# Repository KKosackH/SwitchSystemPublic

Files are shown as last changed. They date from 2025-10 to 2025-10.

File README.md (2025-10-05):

# SwitchSystem  
**NOTE: Files with parts under NDA has been removed**

The **SwitchSystem** PCB was developed as an *add-on discharging solution* for existing **AC home chargers**.  

Although the concept worked, the product was ultimately deemed too **expensive** for production. As a result, the design has been made publicly available.  

All major components were tested and verified functional, including the **HomePlug Green PHY (PLC communication)** with negligible switching losses. However, the PCB was not fully finalized — see the [TO-DO](#to-do) list below for pending improvements.  

---

## Features  
- **Discharging add-on** for existing AC chargers  
- **PLC communication** via HomePlug Green PHY  
- **Integration with Raspberry Pi** through a 2×20 GPIO connector  
- **BatteryBridge compatibility** via JST connector  
- **External I/O**: LCD screen and buttons via JST  
- **Vehicle interface**: IEC 62196 Type 2 AC plug with temperature sensor and lock  
- **Inverter interface**: CANBus development board mounted on Raspberry Pi  

---

## Design Notes  
- The board was later split into multiple PCBs to:  
  - Avoid routing **AC mains** directly onto the main board  
  - Reduce **EMI issues**  
- The newer versions (under NDA) added advanced features such as:  
  - **LTE Cat 4 module**  
  - **CANBus support**  
  - **AMD Xilinx Zynq 7000 SoC**  

> ⚠️ If using the **BatteryBridge v2**, remove the `[3.4] DC-DC converter` and patch the **12 V output** of the BatteryBridge to the 12 V net on the SwitchSystem PCB.  

A full circuit description is available in the [Documentation folder](./Documentation).  

---

## Schematic & PCB  

The schematic is organized using hierarchical sheets, with the root page showing all user-interactable components.  

- **First page schematic**  
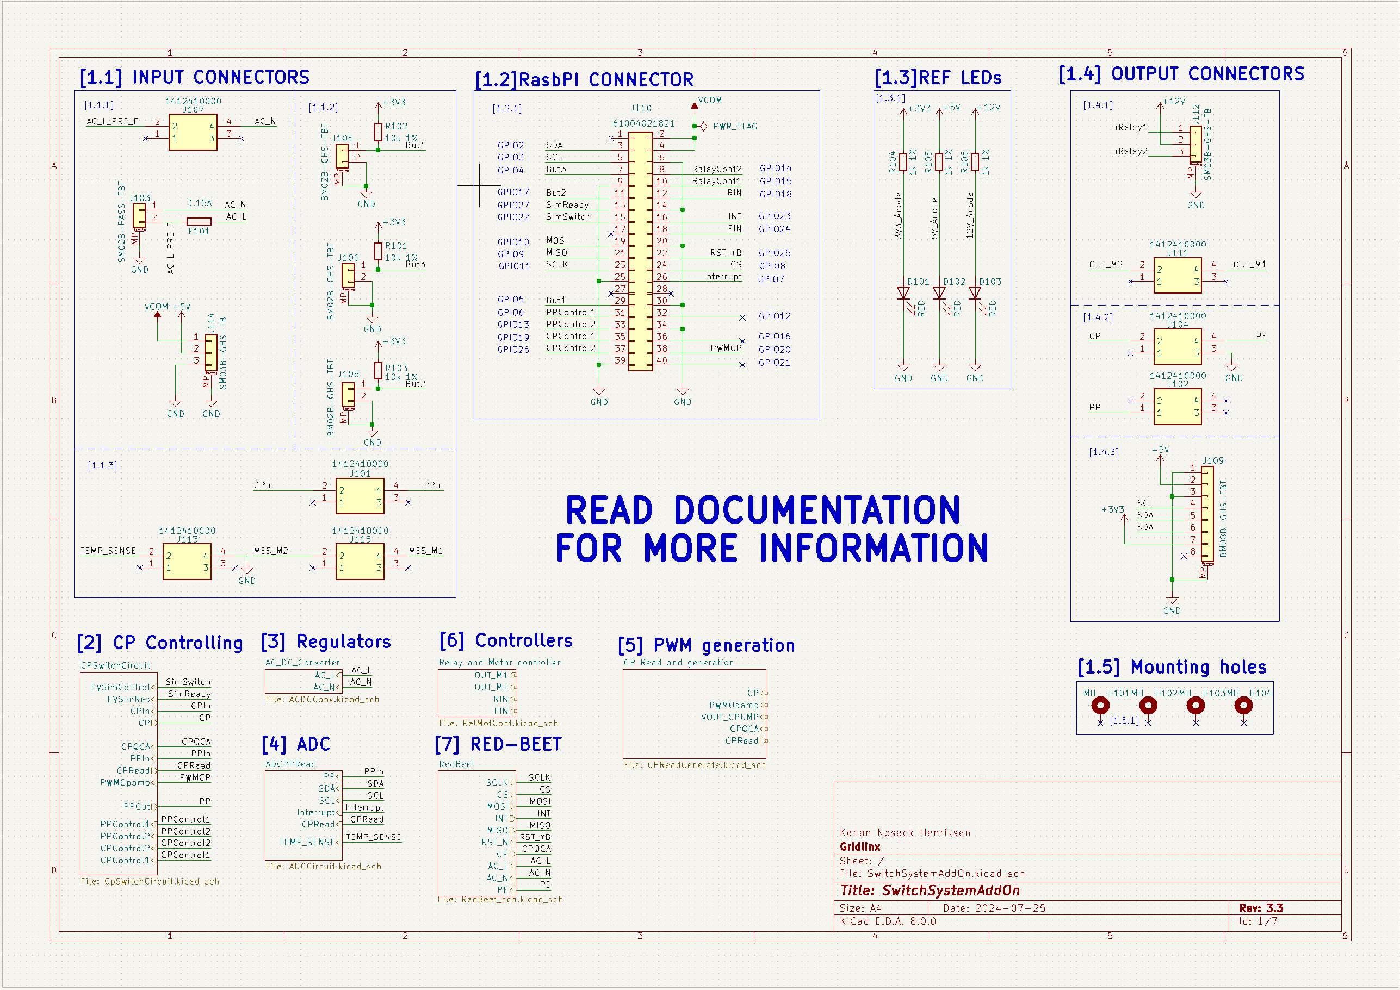
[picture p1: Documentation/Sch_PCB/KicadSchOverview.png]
Schematic Overview
    

- **PCB Front**  
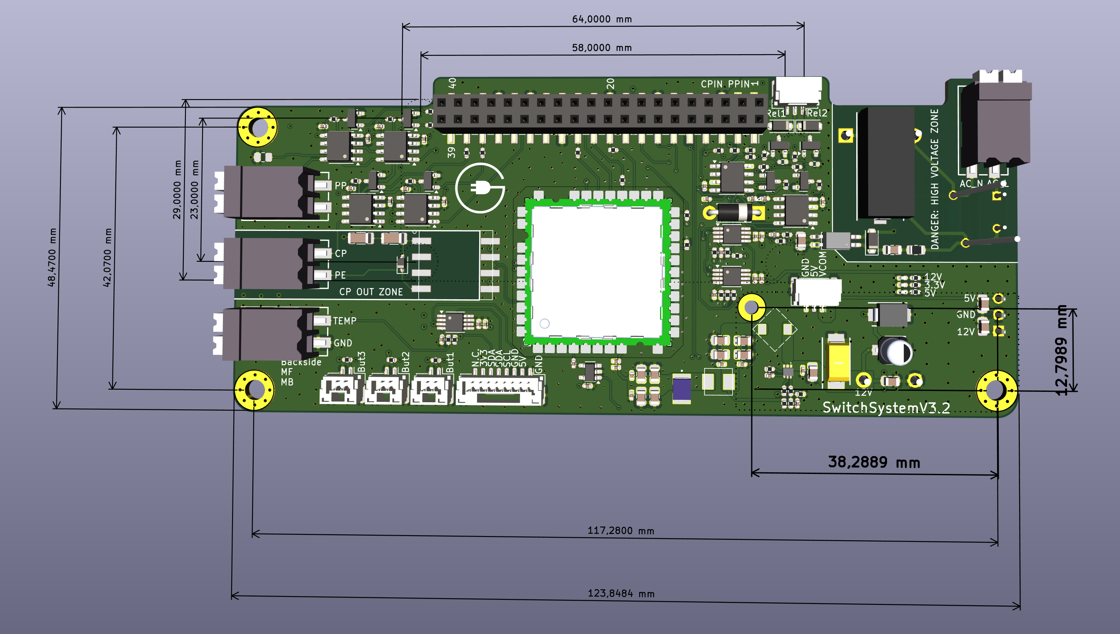
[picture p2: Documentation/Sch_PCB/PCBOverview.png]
PCB Front
    

- **PCB Back**  
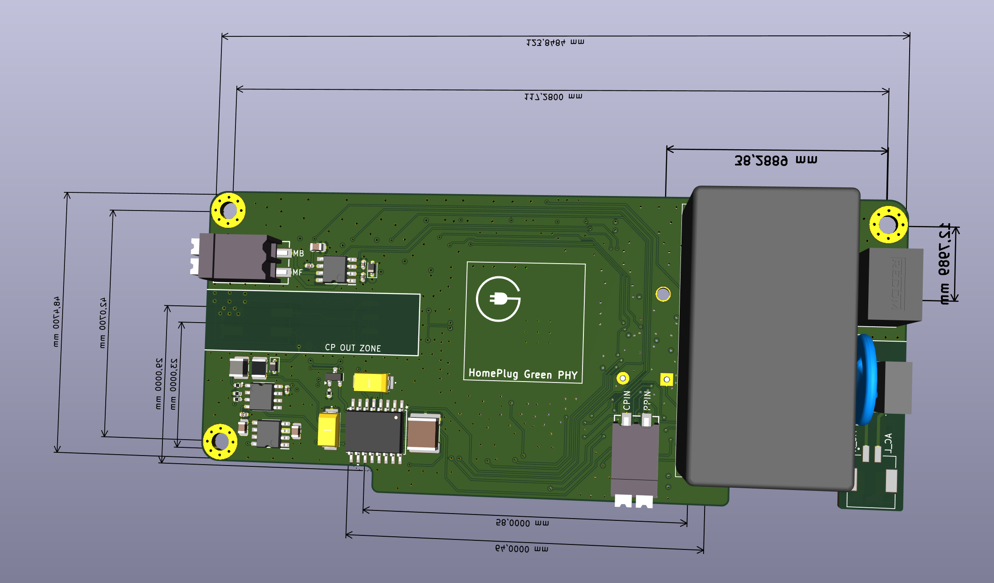
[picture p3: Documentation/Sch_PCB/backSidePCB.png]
PCB Back
    

---

## TO-DO  
Remaining improvements for the PCB design:  

1. Add node names to all nets  
2. Ensure all schematic symbols have correct naming  
3. Add transfer vias  
4. Match SPI line lengths  
5. Change BatteryBridge connector to flat-flex  
6. Add new ADC and connect to motor measurement  
7. Add color coding for cables on PCB  
8. Add low-pass filter to CPRead ADC  
9. Add protected earth connector  
10. Add default charge state for power-loss events  
11. Adjust PCB size for mechanically stable Raspberry Pi mounting  

---

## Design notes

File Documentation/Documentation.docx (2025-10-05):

V3.3 PCB description and documentation
Kenan Henriksen
Gridlinx

07/11-2024

# Overview of components

# SHEET NUMBER 1

## [1.1] Input connectors

## [1.1.1] Power input connectors

  - Screw terminal J107 for AC-mains input
  - SM02B connector J103 for AC connection from EVSE
  - SM03B connector J114 for BatteryBridge connection

## [1.1.2] UI inputs from buttons

  - J105 for button 1
  - J106 for button 2
  - J108 for button 3

## [1.1.3] Type-2 plug inputs

  - J101 terminal for CP- and PP input from EVSE
  - J113 terminal for temperature sensor input
  - J115 terminal for motor state measurement

## [1.1] Detailed Description

## [1.1.1]

The connectors in [1.1.1] are all power input connectors. The J103 is the main AC connector, when using power from the EVSE. This must be connected to the input side of the relay, which will power the PCB from the EVSE. Alternatively, the J107 connector can be used, if the mains will be directly connected to the PCB instead of through the EVSE.
NOTE: Both must never be attached at the same time.

The J114 is used to connecting the BatteryBridge, ensuring that 12V, 3.3V and 5V will always be available, even in the case of a power outage.

## [1.1.2]

The buttons can be used to change the state of the add-on. If button 1/2/3 (J105, J106, J108) is pressed, the following GPIO inputs will be pulled LOW: GPIO5, GPIO17, GPIO4.

The current configuration only uses 2 buttons (1 and 2), which respectively change to state charging and discharging.

## [1.1.3]

The J101 connector is used for connecting the CP and PP lines from the EVSE. The CP line is connected by the WHITE cable from the plug, and the BLACK cable for the PP line.

The J113 line is used for connecting the temperature sensor. The GREY cable is used for the measurement and the BROWN is used for GROUND. The output is connected to the temperature ADC [4.1.2].

Note: The following resistances is given for different conditions:
IF (TEMP < 110) THEN R == 790 to 1279

IF (TEMP > 110) THEN R == 1280 to 1420

IF (HYSTERIES == TRUE) THEN R < 1200 BEFORE RESUMING

IF (R < 790 OR R > 1420) THEN STOP

SEE TYPE 2 PLUG DATASHEET FOR FURTHER INFORMATION

The J115 is used for the connection of the motor. The BLUE/RED and BLUE/BROWN cable is used for connecting the motor. The BLUE/RED is used for locking the motor and BLUE/BROWN for unlocking. The motor is controlled by GPIO24 (FIN) and GPIO18 (RIN). The GPIO lines are connected to the full H-Bridge, allowing for 12V controlling of the motor, as required by the datasheet.

Note: The following conditions are given for the motor:

WHEN LOCK APPLY FIN FOR MAX 600ms

WHEN UNLOCK APPLY RIN FOR MAX 600ms

SEE DATASHEET FOR TYPE 2 CONNECTOR FOR FURTHER INFORMATION

IF FIN == HIGH THEN OUT_M1 == 12V (LOCK)

IF RIN == HIGH THEN OUT_M2 == 12V (UNLOCK)

## [1.2] Raspberry PI connector

## [1.2.1] Raspberry PI female pin header

  - J110 Raspberry Pi connector

## [1.2] Detailed description

## [1.2.1]

The Raspberry Pi uses the following interfaces: SPI, I2C and GPIO.

The SPI line is only used for controlling the RED-BEET [7.1.1], and is using the following pins: GPIO10, GPIO9, GPIO11, GPIO23, GPIO8.

The I2C line is used for controlling all 3 ADCs [4.1.1]/[4.1.2]/[4.1.3] and the screen [1.4.3]. The line is using the pins: GPIO2, GPIO3, GPIO7.

The GPIO lines are divided into different parts for controlling:

Buttons (1/2/3) are using GPIO5, GPIO17 and GPIO4 respectively.

For controlling the EVSE state, the following pins are used: GPIO27 and GPIO22. When pulling GPIO27 HIGH, the voltage level on the CP input line drops from 12V → 9V, i.e., Changing CP state from A → B. When pulling GPIO22 HIGH, the voltage level on the CP input line drops further. This results in a state change from B → C, letting current flow from the EVSE. Note: GPIO27 must be pulled HIGH and maintained HIGH before pulling this pin HIGH.

The following GPIO lines are switching between sending the CP and PP line from the EVSE through to the EV and sending the generated CP and PP line from the add-on through: GPIO6, GPIO13, GPIO19, GPIO26.
If GPIO13 is pulled HIGH, the PP line from the EVSE is sent through, and if GPIO6 is pulled HIGH, the generated PP line is sent through. If GPIO19 is pulled HIGH, the CP line from the EVSE is sent through, and if GPIO26 is pulled HIGH, the generated CP signal is sent through.

Controlling the relay is done through GPIO14 and GPIO15. Only one of these pins is needed for controlling the relay. In the current setup GPIO15 is used.

Note: Circuit description:

The circuit is an open-collector circuit ie. the coil at the relay is always at 12V.

When closing the relay pull RelayCont1 (GPIO15) or RelayCont2 (GPIO14) (whichever is connected to the relay) HIGH.

GPIO18 and GPIO24 are used for controlling the motor. When locking the motor GPIO24 is pulled HIGH, and when unlocking the motor GPIO18 is pulled HIGH. See section [1.1.3] for further details.

GPIO20 is used for generating the PWM signal for the CP line. This pin must use a frequency of 1kHz and must be turned on when SLAC must be established.
Note: Use 5% OR 100% duty-cycle for SLAC.

## [1.3] Reference LEDs

## [1.3.1] LEDs

  - UI LEDs for 3.3V, 5V and 12V

## [1.3] Detailed description

## [1.3.1]

The LEDs are used to verify correct voltage levels on the board. If all 3 LEDs are illuminated, the correct voltage levels are on the board.

## [1.4] Output connectors

## [1.4.1] Plug and motor connectors

  - J112 for relay coil connection
  - J111 for Type-2 plug motor controlling

## [1.4.2] Output connectors for ISO15118/IEC61851 communication

  - J104 for CP output and Protected Earth
  - J102 for PP output

## [1.4.3] Display connector

  - J109 for I2C communication interface for Joy-IT display

## [1.4] Detailed description

## [1.4.1]

The J112 connector is used for connecting the relay. Only cables for pin 1 and pin 2 are connected, as only 1 pin is used for controlling the relay.
Note: See section [1.2.1] for further information regarding GPIO configurations.

The J111 is used for connecting the motor in the plug to the PCB.
Note: See section [1.2.1] for further information regarding GPIO configurations.

## [1.4.2]

The J104 connector is used for the connection of the CP output line and the PE for the EV. The J102 connector is used for the connection of the PP output line.
Note: See section [1.1.3] for cable configuration.

## [1.4.3]

The J109 connector is used for connecting the Joy-IT screen. The connector is a JST type connector, and the cables are wired directly to the pins, therefore proper connection is always ensured.

Note: See section [1.2.1] for interface description.

## [1.5] Mounting holes

## [1.5.1] Mounting holes for box mount and BatteryBridge mounting

  - H101-H102 for box mounting
  - H103 for box mounting and BatteryBridge mounting
  - H104 for BatteryBridge mounting

# SHEET NUMBER 2

## [2.1] CP switches and EV simulator circuit

## [2.1.1] Switches for CP line and PP line

  - U203A switch for ISO communication
  - U206A switch for IEC communication
  - U204A switch for PP line for IEC communication
  - U207A switch for PP line for ISO communication

## [2.1.2] Power inputs for switches

## [2.1.3] EV simulator circuit

  - U205A changes CP state A → B
  - U208A changes CP state B → C

## [2.1] Detailed description

## [2.1.1]

To switch between the CP/PP lines and EV simulation ADG417 Analog Switches are used. These switches can handle negative voltages up to ±22V, therefore making them a good fit to control the CP line. The switches are active LOW and need 5V logic levels for controlling. The power inputs must be tied to 5V for controlling, and ±12V for controlling CP line voltage levels.

Note: See Section [2.2] for further description of the high-side switches.

Note: See section [2.3] for further description of the -12V power input circuitry.

## [2.1.2]

Power inputs for the ADG417 switches. Section [2.4] describes decoupling capacitors.

## [2.1.3]

This circuit is the EV simulator circuit, as described in IEC 61851-1. The circuit is used for simulating an EV connection to the EVSE, therefore leading to power transfer from the EVSE. The analog switches are used to control the circuit.

## [2.2] Switch enable circuits

## [2.2.1] Control for CP state B -> C

## [2.2.2] Control for ISO communication

## [2.2.3] Control for PP line for ISO communication

## [2.2.4] Control for PP line for IEC communication

## [2.2.5] Control for IEC communication

## [2.2.6] Control for CP state A -> B

## [2.2] Detailed description

The switch-enable circuits that allow 5V controlling of the analog switches, as required by the datasheet. The circuit works as a high-side switch, therefore when pulling a transistor base HIGH, the output of the switch will be pulled LOW, as required by the analog switches.

## [2.3] Charge pump circuit

## [2.3.1] Charge pump 12V -> -12V inverter circuit

## [2.3] Detailed description

## [2.3.1]

This circuit is used for inverting the 12V into -12V. To drive OP-AMPs, a transistor with its base must be connected to ground, and its collector is connected to the output i.e., -12V. The circuit can deliver a maximum of 100mA, as also documented in the schematic of the PCB.

## [2.4] Decaps

## [2.4.1] Decaps for switches

## [2.4] Detailed description

## [2.4.1]

Decoupling capacitors for the switches. Might not be needed, can probably be removed for BOM reduction. These are all 100nF capacitors, and are placed near all input pins on the analog switches.

# SHEET NUMBER 3

## [3.1] AC/DC converter

## [3.1.1] Mains AC to 12V DC converter

## [3.1] Detailed description

## [2.3.1]

This AC/DC converter converts the 230V AC into 12V DC for the board. The current configuration uses a module to lower the complexity of the board.

## [3.2] 12V -> 5V DC/DC converter

## [3.1.1] 12V -> 5V DC/DC converter from either BatteryBridge or AC/DC converter

## [3.2] Detailed description

## [3.2.1]

For board version 3.3 and later, a buck converter is used for 12V → 5V conversion for the board. This converter has been chosen due to higher efficiency than the old version as described in section [3.4].

## [3.3] 12V -> 3.3V DC/DC converter

## [3.1.1] 12V -> 3.3V DC/DC converter for RED-BEET and other 3.3V circuitry

## [3.3] Detailed description

## [3.3.1]

This circuit is a high-performance 12V → 3.3V buck converter with both first and second stage filtering for the RED-BEET. This specific converter is used as recommended by 8Devices for this specific module. It also supplies the rest of the board with 3.3V and can deliver 1A.

## [3.4] 12V -> 5V DC/DC converter (old design)

## [3.1.1] 12V -> 5V DC/DC converter from either BatteryBridge or AC/DC converter

## [3.4] Detailed description

## [3.4.1]

This is the old 12V → 5V converter. It is still on the board, if the buck converter is nonfunctional, however will not be placed as shown by the DNP symbol. Only on board as a back-up in case of failure with buck converter.

# SHEET NUMBER 4

## [4.1] ADCs

## [4.1.1] ADC for reading the PP line

## [4.1.2] ADC for temperature reading in plug

## [4.1.3] ADC for reading the voltage level at the CP output line

## [4.1] Detailed description

## [4.1.1]

This ADC converts the PP resistance into digital signal for the Raspberry Pi. The Address is 0x50.

## [4.1.2]

This ADC converts the resistance of the temperature sensor output into digital signal for the Raspberry Pi. The address is 0x51. The resistance and its respective voltage is shown in notes below.

Note: IF (R == 790 to 1279) THEN VIN_ADC3 == 1.457V to 1.852V

IF (R == 1280 to 1420) THEN VIN_ADC == 1.852V to 1.936V

## [4.1.3]

This ADC converts the voltage level on the CP line into digital signal for the Raspberry Pi. The address is 0x52.

# SHEET NUMBER 5

## [5.1] PWM generation- and read-circuit

## [5.1.1] PWM generation for the CP line

## [5.1.2] Voltage divider circuit for reading the CP voltage level

## [5.1] Detailed description

## [5.1.1]

This circuit is a complete copy of the circuit described in the DB2605 EV Charging Controller Datasheet (section 5.1). It is a basic OP-AMP circuit, which gives a 12V HIGH output when PWM signal is HIGH and -12V output when PWM signal is LOW.

## [5.1.2]

This circuit is a copy of the circuit described in the DB2605 EV Charging Controller Datasheet (section 5.2). The circuit has been modified to be in the range of 0V-3.3V for the ADC. The output of the circuit is connected to the input of the ADC in section [4.1.3]

# SHEET NUMBER 6

## [6.1] Relay control circuit

## [6.1.1] Control circuit for relay

## [6.1] Detailed description

## [6.1.1]

This circuit is used for controlling the 12V coil on the relay. The diodes are required for when the coil collapses, so that the pins on the transistor will not be destroyed.

Note: See section [1.2.1] for further circuit description.

## [6.2] Motor control circuit

## [6.2.1] H-bridge motor driver

## [6.2] Detailed description

## [6.2.1]

This motor driver is a full H-bridge. It is used to control the 12V motor in the plug.

Note: See section [1.2.1] and [1.1.3] for further description.

# SHEET NUMBER 7

## [7.1] RED-BEET module

## [7.1.1] RED-BEET module for Homeplug Green PHY communication

## [7.1] Detailed description

## [7.1.1]

Under NDA

## [7.2] Zero-crossing circuit

## [7.2.1] Zero-crossing circuit for RED-BEET module

## [7.2] Detailed description

## [7.2.1]

Under NDA

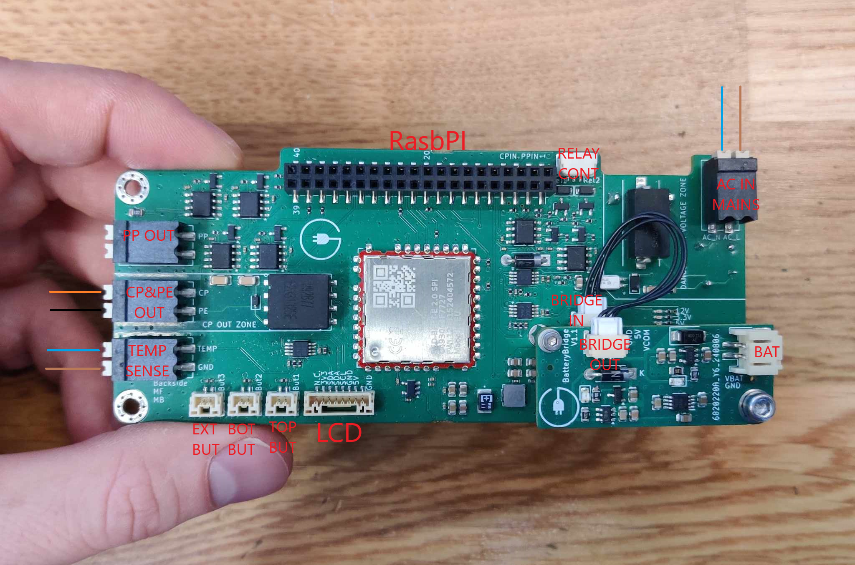
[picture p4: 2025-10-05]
Documentation/PhysicalPCB/FrontWithComments.png

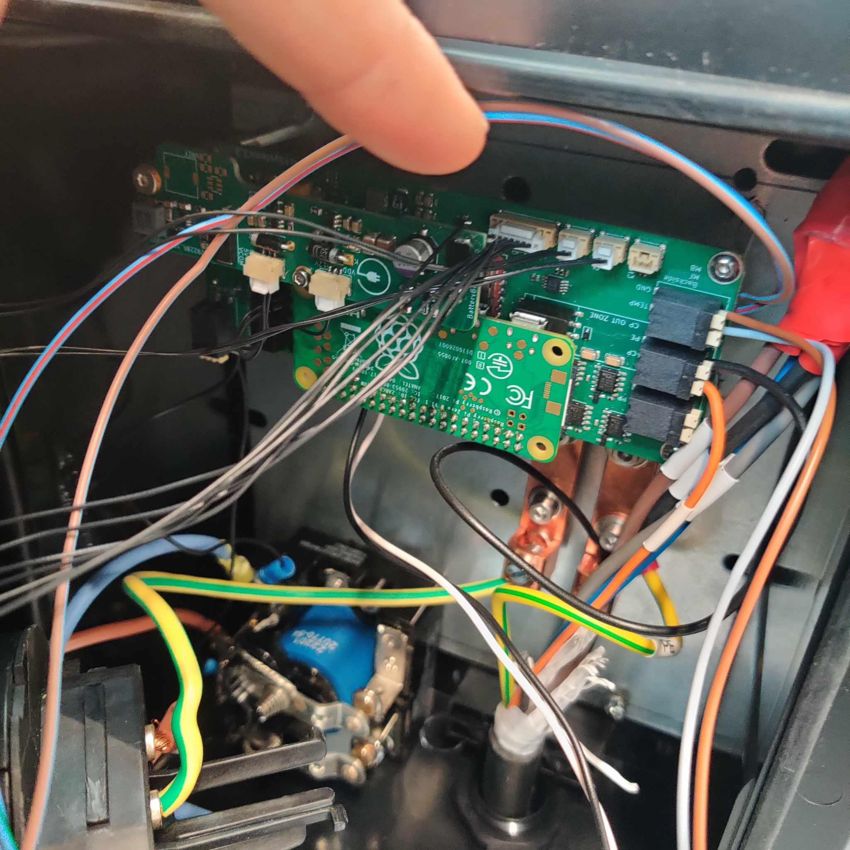
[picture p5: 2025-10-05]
Documentation/PhysicalPCB/InsideAddOn.jpg

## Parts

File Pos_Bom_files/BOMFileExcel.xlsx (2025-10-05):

Reference | Value | Datasheet | Footprint | Description | Qty | DNP | Manufacturer_Name | Manufacturer_Part_Number | Generic | Supplier link
U502 | YT-35636 | ~ | Footprints:YT-35636 | Power Line Communication Transformer YT-35636 (292877) | 1 |  | Codico | 292877 | No | https://www.codico.com/en/yt-35636-292877
U501 | LM321 | http://www.ti.com/lit/ds/symlink/lm321.pdf | Package_TO_SOT_SMD:SOT-23-5 | Low Power Single Operational Amplifier, SOT-23-5 | 1 |  | Texas Instruments | LM321LVIDCKR | No | https://www.mouser.dk/ProductDetail/STMicroelectronics/LMV321LILT?qs=0PAMiCYhSzEO4kUYl9lr1Q%3D%3D&gad_source=1
U401,U402,U403 | ADC081C021CIMM | http://www.ti.com/lit/ds/symlink/adc081c021.pdf | Package_SO:MSOP-8_3x3mm_P0.65mm | IC ADC 8BIT SAR 8VSSOP | 3 |  | Texas Instruments | ADC081C021CIMM/NOPB | No | https://www.digikey.dk/en/products/detail/texas-instruments/ADC081C021CIMM-NOPB/2092941
U209 | LT1054CSW-PBF | LT1054CSW-PBF | Footprints:SO-16_SW_LIT | IC REG CHARG PUMP INV 16SOIC | 1 |  | Analog Devices Inc. | LT1054CSW#PBF | No | https://www.digikey.dk/en/products/detail/analog-devices-inc/LT1054CSW-PBF/889554
U203,U204,U205,U206,U207,U208 | ADG417BR | https://www.analog.com/media/en/technical-documentation/data-sheets/ADG417.pdf | Package_SO:SOIC-8_3.9x4.9mm_P1.27mm | Single SPST Monolithic LC²MOS Analog Switch, normally OFF, 35Ohm Ron, SOIC-8 | 6 |  | Analog Devices Inc. | ADG417BR | No | https://www.digikey.dk/en/products/detail/analog-devices-inc/ADG417BR/612264
U201 | LF353 | ~ | Footprints:SOIC127P599X175-8N | IC OPAMP GP 2 CIRCUIT 8SOIC | 1 |  | Texas Instruments | LF353MX/NOPB | No | https://www.digikey.dk/en/products/detail/texas-instruments/LF353MX-NOPB/334933
RV301 | B72214S0351K101 | ~ | Footprints:VAR_B72214S0131K101 | VARISTOR DISC 14MM | 1 |  | EPCOS - TDK Electronics | B72214S0351K101 | No | https://www.digikey.dk/en/products/detail/epcos-tdk-electronics/B72214S0351K101/3500928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
R508 | 820k 1/3W | ~ | Resistor_SMD:R_0805_2012Metric | 820K OHM 1% 1/3W 0805 | 1 |  | ~ | ~ | Yes | ~
R507 | 39k 1% | ~ | Resistor_SMD:R_0402_1005Metric | 39K OHM 1% 1/16W 0402 | 1 |  | ~ | ~ | Yes | ~
R506 | 100R 1% | ~ | Resistor_SMD:R_0402_1005Metric | 100 OHM 1% 1/16W 0402 | 1 |  | ~ | ~ | Yes | ~
R502,R503,R504 | 0R | ~ | Resistor_SMD:R_0402_1005Metric | 0R 1/16W 0402 | 3 |  | ~ | ~ | Yes | ~
R305 | 13k 1% | ~ | Resistor_SMD:R_0402_1005Metric | 13K OHM 1% 1/16W 0402 | 1 |  | ~ | ~ | Yes | ~
R304 | 40k2 1% | ~ | Resistor_SMD:R_0402_1005Metric | 40.2K OHM 1% 1/16W 0402 | 1 |  | ~ | ~ | Yes | ~
R303,R306 | 10R 1% | ~ | Resistor_SMD:R_0402_1005Metric | 10 OHM 1% 1/16W 0402 | 2 |  | ~ | ~ | Yes | ~
R302 | 47k 1% | ~ | Resistor_SMD:R_0402_1005Metric | 47K OHM 1% 1/16W 0402 | 1 |  | ~ | ~ | Yes | ~
R301 | 6R8 | ~ | Footprints:RESM17073X710N | SMQW3W 6R8 5% | 1 |  | TE Connectivity Passive Product | SMQW36R8JT | No | https://www.digikey.dk/en/products/detail/te-connectivity-passive-product/SMQW36R8JT/21316478
R223 | 1K3 1% | ~ | Resistor_SMD:R_0402_1005Metric | 1300 OHM 1% 1/16W 0402 | 1 |  | ~ | ~ | Yes | ~
R222 | 2K74 1% | ~ | Resistor_SMD:R_0402_1005Metric | 2.74K OHM 1% 1/16W 0402 | 1 |  | ~ | ~ | Yes | ~
R221 | 1k 5% | ~ | Resistor_SMD:R_0805_2012Metric | ~ | 1 | DNP | ~ | ~ | ~ | ~
R212 | 220R 1% | ~ | Resistor_SMD:R_1210_3225Metric | 220 OHM 1% 1/2W 1210 | 1 |  | ~ | ~ | Yes | ~
R210 | 82k 1% | ~ | Resistor_SMD:R_0402_1005Metric | 82K OHM 1% 1/16W 0402 | 1 |  | ~ | ~ | Yes | ~
R209 | 240k 1% | ~ | Resistor_SMD:R_0402_1005Metric | 240K OHM 1% 1/16W 0402 | 1 |  | ~ | ~ | Yes | ~
R207 | 56k 1% | ~ | Resistor_SMD:R_0402_1005Metric | 56K OHM 1% 1/16W 0402 | 1 |  | ~ | ~ | Yes | ~
R202,R204,R307 | 100k 1% | ~ | Resistor_SMD:R_0402_1005Metric | 100K OHM 1% 1/16W 0402 | 3 |  | ~ | ~ | Yes | ~
R109 | 100k 1% | ~ | Resistor_SMD:R_0402_1005Metric | ~ | 1 | DNP | ~ | ~ | ~ | ~
R108 | 0R | ~ | Resistor_SMD:R_0402_1005Metric | ~ | 1 | DNP | ~ | ~ | ~ | ~
R107,R110,R201,R205,R211,R214,R216,R219,R403,R404,R405 | 5k1 5% | ~ | Resistor_SMD:R_0402_1005Metric | 5.1K OHM 5% 1/16W 0402 | 11 |  | ~ | ~ | Yes | ~
R104,R105,R106,R208,R401,R406 | 1k 1% | ~ | Resistor_SMD:R_0402_1005Metric | 1K OHM 1% 1/16W 0402 | 6 |  | ~ | ~ | Yes | ~
R101,R102,R103,R203,R206,R213,R215,R217,R218,R220,R402,R407,R501,R505 | 10k 1% | ~ | Resistor_SMD:R_0402_1005Metric | 10K OHM 1% 1/16W 0402 | 14 |  | ~ | ~ | Yes | ~
Q501 | HMHA281 | https://www.onsemi.com/pub/Collateral/HMHA2801B-D.PDF | Footprints:HMHA281 | Transistor Output Optocouplers Optocoupler Phototransistor | 1 |  | onsemi | HMHA281 | No | https://www.digikey.dk/en/products/detail/onsemi/HMHA281/1051345
Q101,Q103,Q201,Q202,Q203,Q204,Q205,Q206,Q208 | MMBT2222A | ~ | Package_TO_SOT_SMD:SOT-23 | BJT SOT-23 40V 600MA | 9 |  | Diotec Semiconductor | MMBT2222A | No | https://www.digikey.dk/en/products/detail/diotec-semiconductor/MMBT2222A/13163394
PS303 | R-78K5.0-2.0 | https://recom-power.com/pdf/Innoline/R-78K-2.0.pdf | Footprints:R78K5020 | 2.0 Amp SIP3 Single Output | 1 |  | RECOM Power | R-78K5.0-2.0 | No | https://www.mouser.dk/ProductDetail/RECOM-Power/R-78K50-20?qs=Jm2GQyTW%2FbifTVVCmPYVtA%3D%3D&gad_source=1
PS301 | LD15-23B12R2 | ~ | Footprints:CONV_LD15-23B12R2 | AC/DC PCB Mount Power Supply (PSU), 100 to 430VDC, ITE, Household & Medical, 1 Output, 15 W, 12 VDC | 1 |  | MULTICOMP PRO | MP-LD15-23B12R2 | No | https://dk.farnell.com/multicomp-pro/mp-ld15-23b12r2/power-supply-ac-dc-12v-1-25a/dp/3583999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
M101 | BD6231F-E2 | https://componentsearchengine.com/Datasheets/2/BD6231F-E2.pdf | Footprints:SOIC127P620X160-8N | H-Bridge motor driver,36V,1A,SOP8 ROHM BD6231F-E2 Full Bridge Motor Driver 1A, 8-Pin SOP | 1 |  | ROHM Semiconductor | BD6231F-E2 | No | https://www.digikey.dk/en/products/detail/rohm-semiconductor/BD6231F-E2/1739147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
L302 | HER4027 | ~ | HER4027-100M:HER4027-100M | HER4027-100M-R | 1 |  | SAGAMI | 269533 | No | https://www.codico.com/en/her4027-100m-r
L301 | MPI40 | ~ | MPI40_Inductor:MPI40_Inductor | MPIA4015V2-R22-R | 1 |  | EATON ELECTRONICS | 289754 | No | https://www.codico.com/en/mpia4015v2-r22-r
L201 | 220u | ~ | Inductor_SMD:L_1210_3225Metric | FIXED IND 220UH 100MA 10.9OHM SM | 1 |  | EPCOS - TDK Electronics | B82422H1224K000 | No | https://www.digikey.com/en/products/detail/epcos-tdk-electronics/B82422H1224K000/1243410
J112,J114 | SM03B-GHS-TB | ~ | Connector_JST:JST_GH_SM03B-GHS-TB_1x03-1MP_P1.25mm_Horizontal | CONN HEADER SMD R/A 3POS 1.25MM | 2 |  | JST Sales America Inc. | SM03B-GHS-TB | Yes | https://www.digikey.dk/en/products/detail/jst-sales-america-inc/sm03b-ghs-tb/807787
J110 | 61004021821 | ~ | Connector_PinSocket_2.54mm:PinSocket_2x20_P2.54mm_Vertical_SMD | WR-PHD 2.54 MM DUAL SMT SOCKET H | 1 |  | Würth Elektronik | 61004021821 | Yes | https://www.digikey.dk/en/products/detail/w%C3%BCrth-elektronik/61004021821/17737793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
J109 | BM08B-GHS-TBT | ~ | Connector_JST:JST_GH_BM08B-GHS-TBT_1x08-1MP_P1.25mm_Vertical | CONN HEADER SMD 8POS 1.25MM | 1 |  | JST Sales America Inc. | BM08B-GHS-TBT | Yes | https://www.digikey.dk/en/products/detail/jst-sales-america-inc/BM08B-GHS-TBT/807806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
J105,J106,J108 | BM02B-GHS-TBT | ~ | Connector_JST:JST_GH_BM02B-GHS-TBT_1x02-1MP_P1.25mm_Vertical | CONN HEADER SMD 2POS 1.25MM | 3 |  | JST Sales America Inc. | BM02B-GHS-TBT | Yes | https://www.digikey.dk/en/products/detail/jst-sales-america-inc/BM02B-GHS-TBT/807800
J103 | SM02B-PASS-TBT | ~ | Footprints:JST_SM02B-PASS-TBT_LF__SN_ | CONN HEADER SMD R/A 2POS 2MM | 1 |  | JST Sales America Inc. | SM02B-PASS-TBT | Yes | https://www.digikey.dk/en/products/detail/jst-sales-america-inc/sm02b-pass-tbt/1788574
J101,J102,J104,J107,J111,J113 | 1412410000 | https://catalog.weidmueller.com/catalog/Start.do;jsessionid=2545CA0BAB23962A974316635BA0C98D?ObjectID=1412410000&page=Product | Footprints:1412410000 | Printed circuit board terminals, 3.50 mm, Number of poles: 2, 90, black, PUSH IN with actuator, Clamping range, max. [rated connection]: 1.5 mm, Tape | 6 |  | Weidmuller | 1412410000 | No | https://eu.mouser.com/ProductDetail/Weidmuller/1412410000?qs=WJDKaGZ8K%252B4z3kQbFrn6wA%3D%3D
IC301 | MP1479GTF-Z | https://www.mouser.jp/datasheet/2/277/MP1479-1578710.pdf | Footprints:MP1479GTFZ | Switching Voltage Regulators 1A, 3.9-18V, 800kHz, High-Efficiency, Synchronous, Step-Down Converter In SOT 563.,vin | 1 |  | Monolithic Power Systems (MPS) | MP1479GTF-Z | No | https://www.digikey.dk/en/products/detail/monolithic-power-systems-inc/MP1479GTF-Z/18089864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
IC201 | TC1044SCOA | https://datasheet.datasheetarchive.com/originals/distributors/Datasheets-18/DSA-359983.pdf | Footprints:SOIC127P600X175-8N | IC REG CHARG PUMP INV 20MA 8SOIC | 1 |  | Microchip Technology | TC1044SCOA | No | https://www.digikey.dk/en/products/detail/microchip-technology/TC1044SCOA/442741
H101,H102,H103,H104 | MH | ~ | -- mixed values -- | ~ | 4 |  | ~ | ~ | ~ | ~
F101 | 3.15A | ~ | SS-5H-3.15A-APH:SS5H315AAPH | FUSE BRD MNT 3.15A 300VAC RADIAL | 1 |  | Eaton - Electronics Division | SS-5H-3.15A-APH | No | https://www.digikey.dk/en/products/detail/eaton-electronics-division/SS-5H-3-15A-APH/3719665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
D502 | SM4007PL | ~ | Diode_SMD:D_SOD-123F | DIODE GEN PURP 1KV 1A SOD123FL | 1 |  | Micro Commercial Co | SM4007PL-TP | No | https://www.digikey.dk/en/products/detail/micro-commercial-co/SM4007PL-TP/1793250
D501 | GBLC03C | ~ | Diode_SMD:D_SOD-323 | TVS DIODE 3VWM 7.0VC SOD323 | 1 |  | MDD | GBLC03C | No | https://www.digikey.dk/en/products/detail/nextgen-components/GBLC03C/15648912
D301 | SMBJ20A | https://www.vishay.com/docs/88301/15ke.pdf | Footprints:DIOM5436X261N | TVS DIODE 20VWM 32.4VC DO214AA | 1 |  | Littelfuse Inc. | SMBJ20A | Yes | https://www.digikey.dk/en/products/detail/littelfuse-inc/SMBJ20A/285988
D202 | 1N4934 | http://www.vishay.com/docs/88503/1n4001.pdf | Diode_THT:D_DO-41_SOD81_P7.62mm_Horizontal | DIODE GEN PURP 100V 1A DO204AC | 1 |  | Diotec Semiconductor | 1N4934 | Yes | https://www.digikey.dk/en/products/detail/diotec-semiconductor/1N4934/22193179
D106,D201 | GBLC12C | ~ | Diode_SMD:D_SOD-323 | TVS DIODE 12V VBR MIN 13.3V SO | 2 |  | ANBON SEMICONDUCTOR (INT'L) LIMITED | GBLC12C | No | https://www.digikey.dk/en/products/detail/anbon-semiconductor-int-l-limited/GBLC12C/21774386
D104,D105 | 1N4148W | https://www.vishay.com/docs/85748/1n4148w.pdf | Diode_SMD:D_SOD-123F | DIODE GEN PURP 75V 0.15A SOD123F | 2 |  | Diotec Semiconductor | 1N4148W | No | https://www.digikey.dk/en/products/detail/diotec-semiconductor/1N4148W/18833653
D101,D102,D103 | RED | ~ | LED_SMD:LED_0402_1005Metric | CLEAR RED LED | 3 |  | Lite-On Inc. | LTST-C171KRKT | Yes | https://www.digikey.dk/en/products/detail/liteon/LTST-C171KRKT/386801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
C512 | 2n2 1kV | ~ | Capacitor_SMD:C_0805_2012Metric | 0805 2.2NF 1000V X7R 10% | 1 |  | ~ | ~ | Yes | ~
C510 | 220n | ~ | Capacitor_SMD:C_0805_2012Metric | 220n 100V X7R 0805 | 1 |  | ~ | ~ | Yes | ~
C509,C511 | 2n2 2kV | ~ | Capacitor_SMD:C_1206_3216Metric | 1206 2.2n 2000V X7R 10% | 2 |  | ~ | ~ | Yes | ~
C403,C406,C409 | 4u7 | ~ | Capacitor_SMD:C_0402_1005Metric | 4.7u 25V X5R 0805 | 3 |  | ~ | ~ | Yes | ~
C401,C404,C407 | 470p | ~ | Capacitor_SMD:C_0402_1005Metric | 470p 50V X7R 0402 | 3 |  | ~ | ~ | Yes | ~
C316 | 22u TANT | ~ | Footprints:CAPPM7343X310N | CAP TANT 22UF 10% 35V 2917 | 1 |  | KEMET | T495X226K035ATE300 | Yes | https://www.digikey.com/en/products/detail/kemet/T495X226K035ATE300/12546465
C313 | 10p | ~ | Capacitor_SMD:C_0402_1005Metric | 10p 50V C0G/NP0 0402 | 1 |  | ~ | ~ | Yes | ~
C308,C317,C504,C508 | 1u | ~ | Capacitor_SMD:C_0402_1005Metric | 1u 25V X7R 0402 | 4 |  | ~ | ~ | Yes | ~
C306 | 150u | ~ | 6TPE150MAZB:POSCAP_B1_B1S_B1G_B15G_B2_B2S | CAP TANT POLY 150UF 6.3V 1411 | 1 |  | Panasonic Electronic Components | 6TPE150MAZB | No | https://www.digikey.dk/en/products/detail/panasonic-electronic-components/6TPE150MAZB/4146618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
C305,C311,C312,C319,C503 | 22u | ~ | Capacitor_SMD:C_0805_2012Metric | 22u X5R 16V 0805 | 5 |  | ~ | ~ | Yes | ~
C302,C304,C314,C501 | 1u 0805 | ~ | Capacitor_SMD:C_0805_2012Metric | 1u X7R 25V 0805 | 4 |  | ~ | ~ | Yes | ~
C301 | 10u 20% 16V | ~ | EEE-1CA100SR:EEE1AA220WR | CAP ALUM 10UF 20% 16V SMD | 1 |  | Panasonic Electronic Components | EEE-1CA100SR | No | https://www.digikey.dk/en/products/detail/panasonic-electronic-components/eee-1ca100sr/766045
C208,C506 | 1n | ~ | Capacitor_SMD:C_0402_1005Metric | 1n X7R 50V 0402 | 2 |  | ~ | ~ | Yes | ~
C206,C207 | 100uF | ~ | Footprints:T491C | Tantalum Capacitors - Solid SMD 16V 100uF 2312 10% ESR=1ohms | 2 |  | KEMET | T491C107K016AT | No | https://www.mouser.dk/ProductDetail/KEMET/T491C107K016AT?qs=Si2vDv5E4YMke5HCn79NYA%3D%3D&gad_source=1
C204 | 2uF | ~ | Capacitor_SMD:C_2220_5750Metric | CAP CER 2UF 200V X7R 2220 | 1 |  | KEMET | C2220C205K2RLC7800 | Yes (better or equivalent) | https://www.digikey.dk/en/products/detail/kemet/C2220C205K2RLC7800/16266383
C103,C201,C202,C309,C310,C318 | 10u | ~ | Capacitor_SMD:C_0805_2012Metric | 10u X7R 16V 0805 | 6 |  | ~ | ~ | Yes | ~
C101,C102,C104,C203,C205,C209,C210,C211,C212,C213,C214,C215,C216,C217,C218,C219,C220,C303,C307,C315,C402,C405,C408,C502,C505,C507 | 100n | ~ | Capacitor_SMD:C_0402_1005Metric | 100n X7R 25V 0402 | 26 |  | ~ | ~ | Yes | ~
A501 | RED-BEET_2.0 | ~ | Footprints:RED-BEET_2.0 | RED-BEET-E 2.0 SPI (EVSE) Module - SPI pre-configured | 1 |  | Codico | 317986 | No | https://www.codico.com/de/red-beet-e-2-0-evse-module

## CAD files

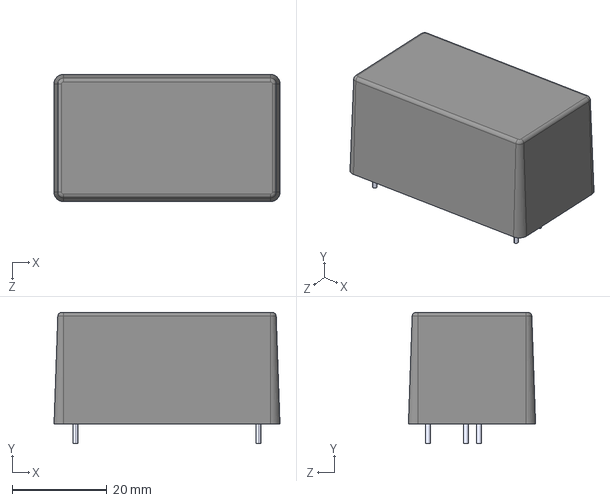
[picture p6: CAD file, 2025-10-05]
LibFiles/3DModels/LD15-23B12R2.step
47.6 x 27.6 x 26.8 mm

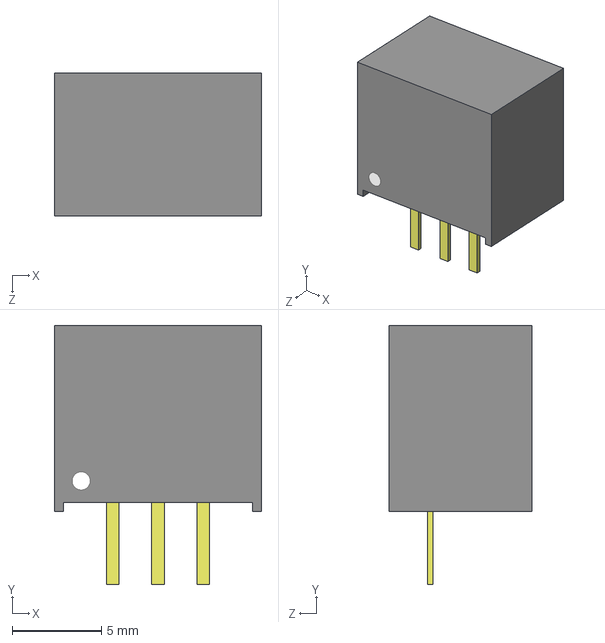
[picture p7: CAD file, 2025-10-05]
LibFiles/3DModels/P78E05-1000.stp
11.6 x 14.5 x 8.00 mm

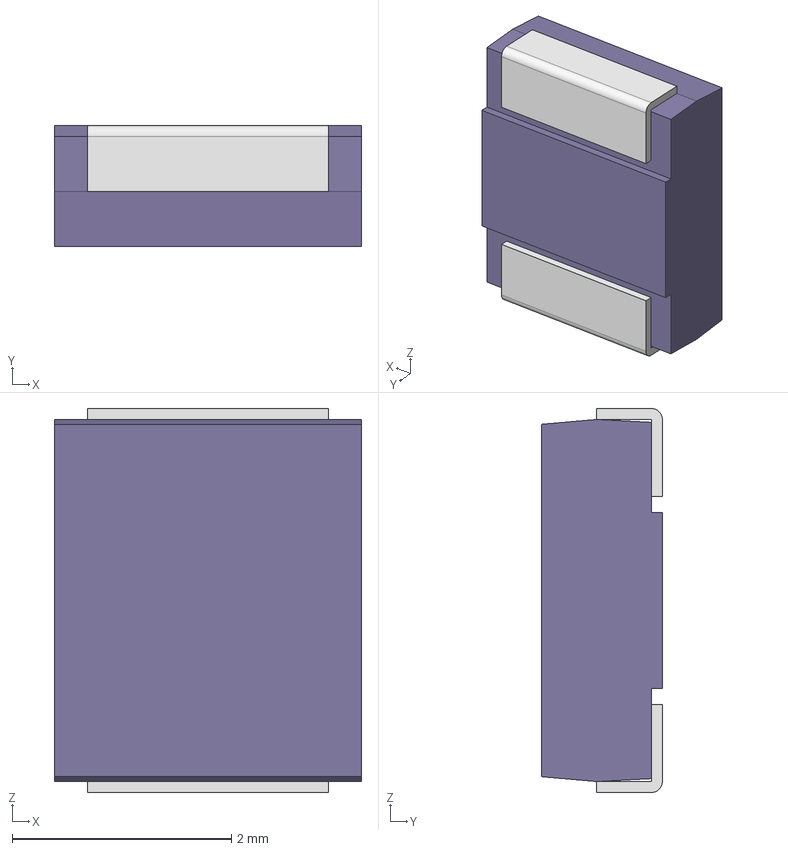
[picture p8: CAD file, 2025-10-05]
LibFiles/3DModels/6TPE150MAZB.stp
2.80 x 1.10 x 3.50 mm
mold-B1G
flame-B1G x 2

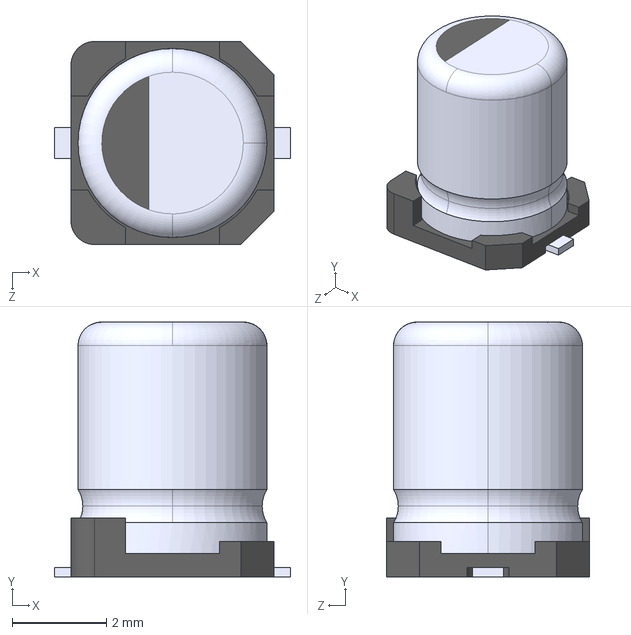
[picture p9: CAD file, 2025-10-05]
LibFiles/3DModels/EEE-1CA100SR.STEP
5.00 x 5.40 x 4.30 mm

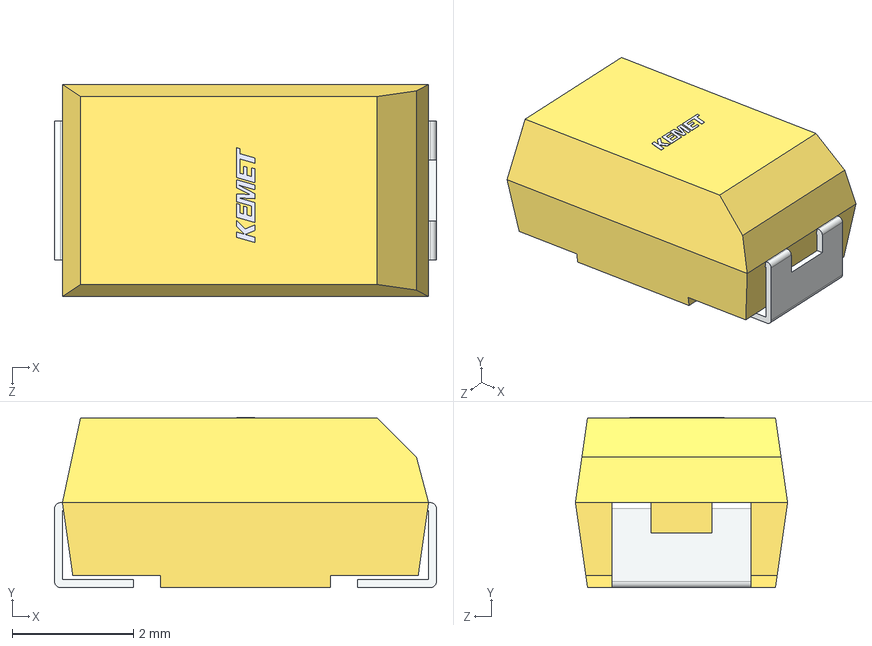
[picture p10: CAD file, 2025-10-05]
LibFiles/3DModels/T491C107K016AT.stp
6.30 x 2.81 x 3.50 mm

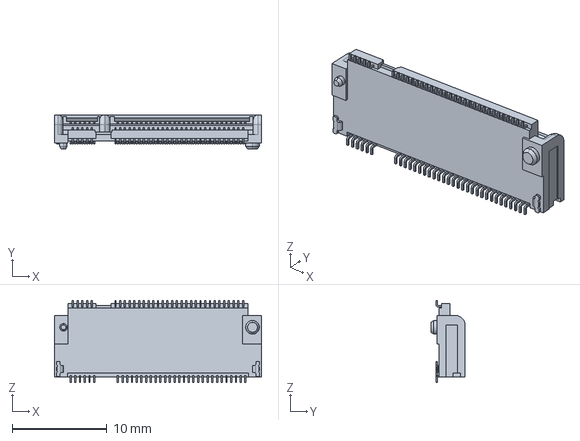
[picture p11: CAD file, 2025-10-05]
LibFiles/3DModels/c-2199119-5-c-3d.stp
21.9 x 3.62 x 8.70 mm

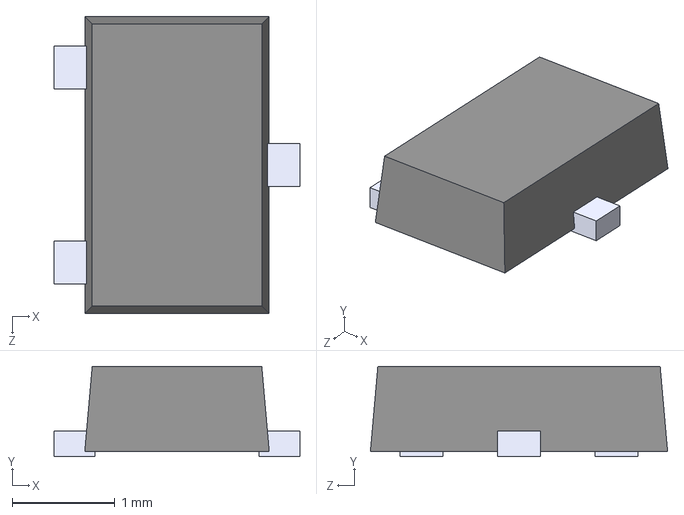
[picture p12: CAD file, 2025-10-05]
LibFiles/3DModels/SSM3K2615R,LF.STEP
2.40 x 0.88 x 2.90 mm

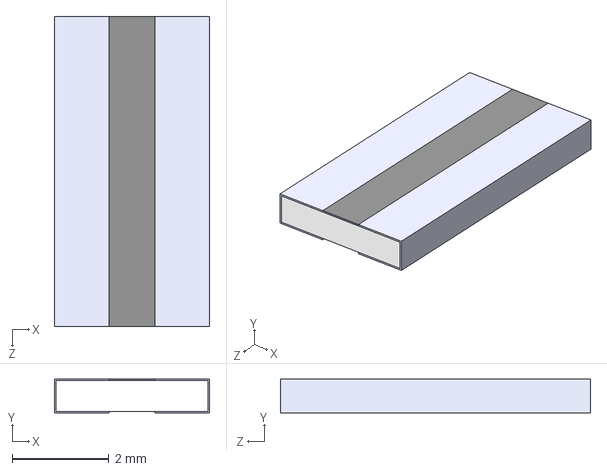
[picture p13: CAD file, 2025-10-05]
LibFiles/3DModels/LTR100JZPF3R00.STEP
3.20 x 0.7 x 6.40 mm

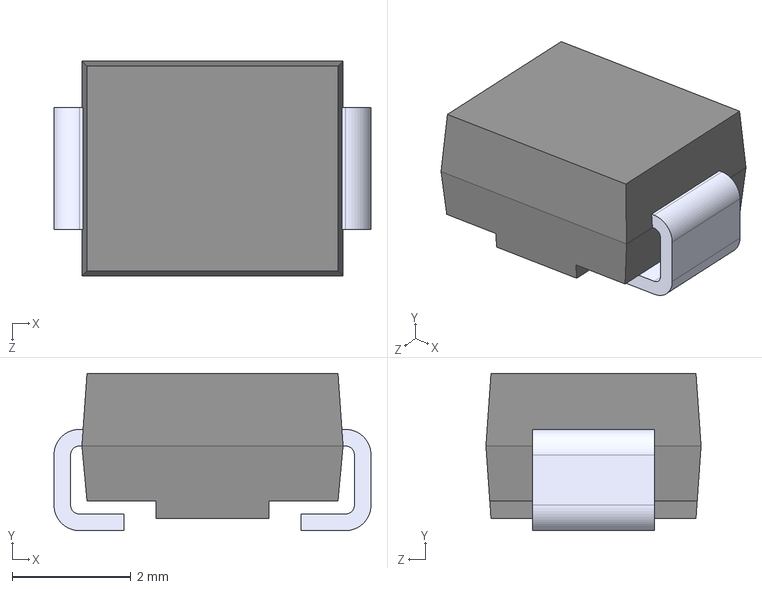
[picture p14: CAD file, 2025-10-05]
LibFiles/3DModels/SMBJ20A.STEP
5.34 x 2.65 x 3.62 mm

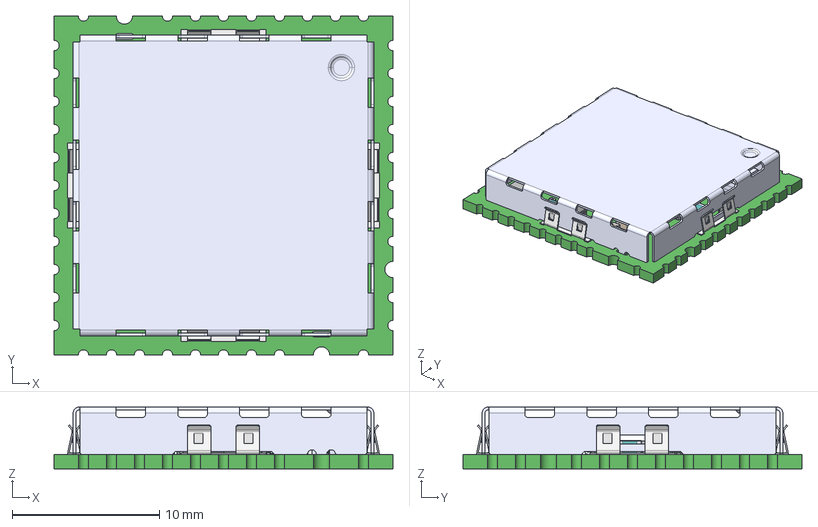
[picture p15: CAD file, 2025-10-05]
LibFiles/3DModels/RED-BEET_2.0_r01.step
23.0 x 23.0 x 4.19 mm
Ferrite x 64
PWL_120_M01_01
s0971-46 x 4
Extruded x 3
vls252012cx-1 v2
User Library-sc70-3 x 2
CircuitWorks-SOD123 x 4
User Library-CR1005-0402 x 2

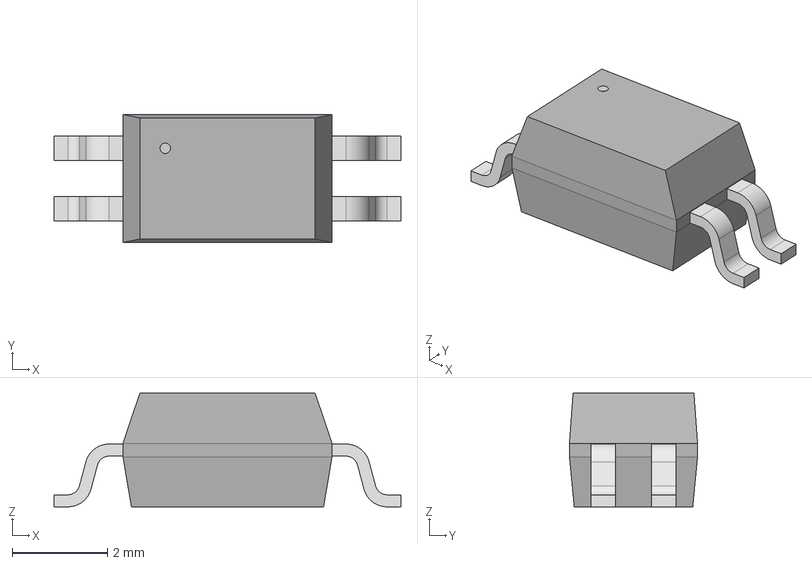
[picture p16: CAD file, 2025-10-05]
LibFiles/3DModels/MFP-4_4P40X2P69_ONS.step
7.29 x 2.69 x 2.39 mm

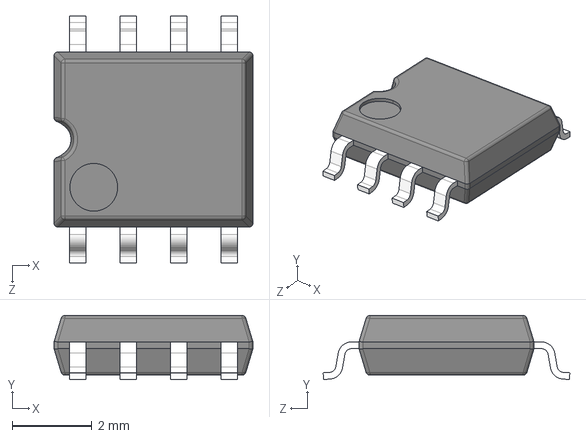
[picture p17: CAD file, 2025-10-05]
LibFiles/3DModels/BD6231F-E2.stp
5.00 x 1.61 x 6.20 mm

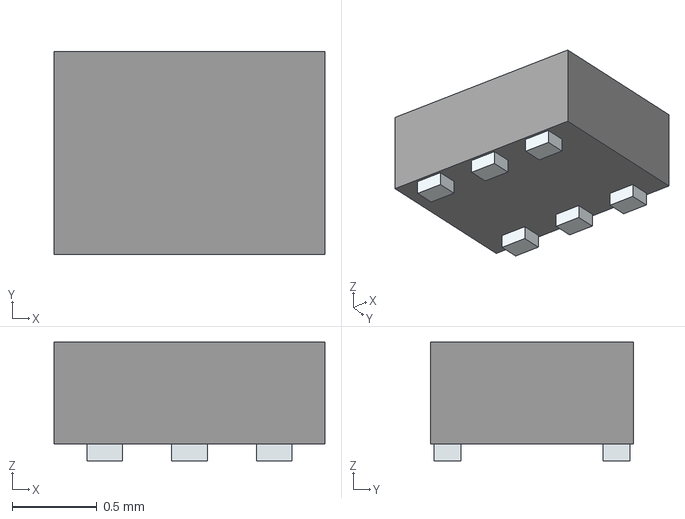
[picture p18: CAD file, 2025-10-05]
LibFiles/3DModels/MP1479GTF-Z.stp
1.60 x 1.20 x 0.7 mm
Pins

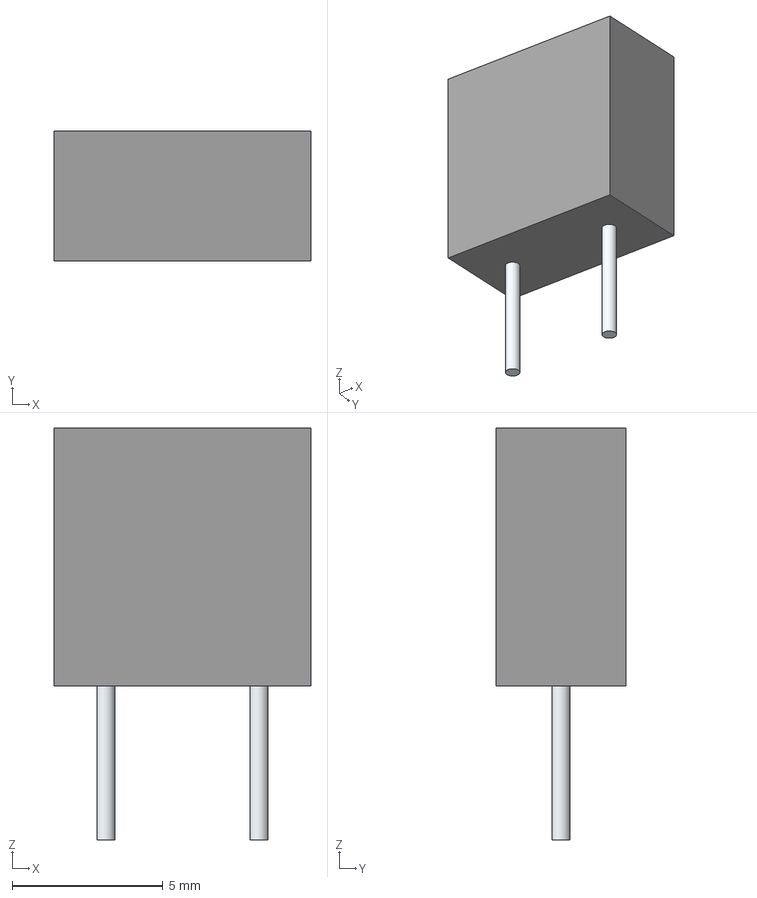
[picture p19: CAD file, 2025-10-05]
LibFiles/3DModels/SS-5H-3.15A-APH.stp
8.50 x 4.30 x 13.7 mm
Leads

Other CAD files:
LibFiles/3DModels/R-78K5.0-2.0.stp
LibFiles/3DModels/SMQW36R8JT.stp
LibFiles/3DModels/691709710302.stp
LibFiles/3DModels/1412410000.stp
LibFiles/3DModels/009276002021106.stp
LibFiles/3DModels/786463001.stp
LibFiles/3DModels/B72214S0131K101.stp

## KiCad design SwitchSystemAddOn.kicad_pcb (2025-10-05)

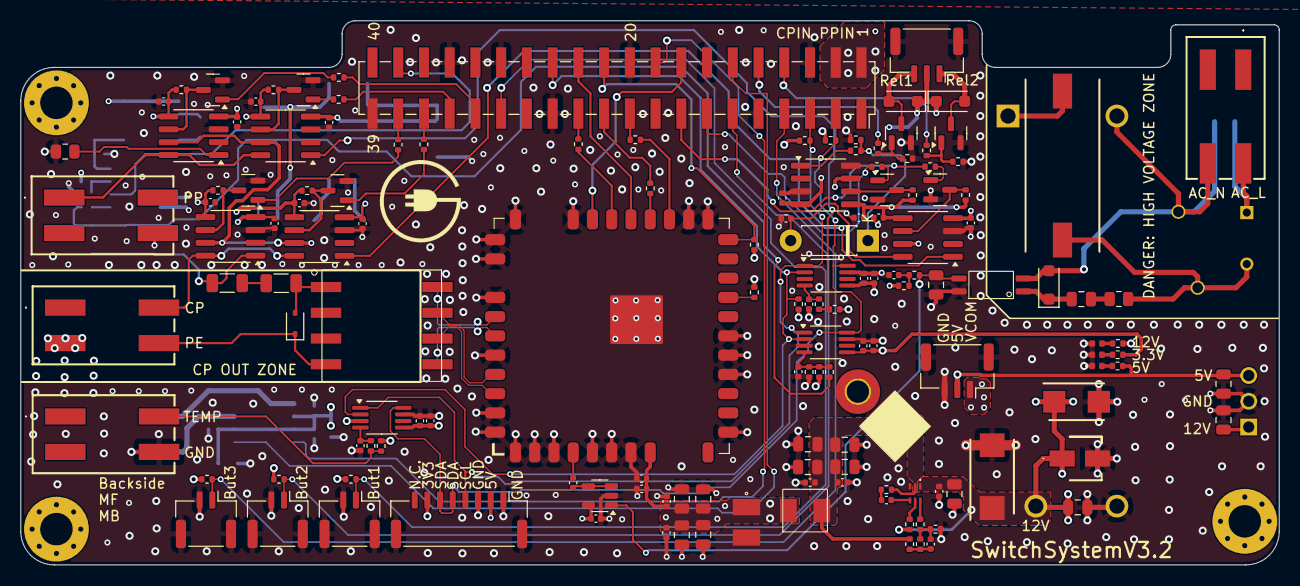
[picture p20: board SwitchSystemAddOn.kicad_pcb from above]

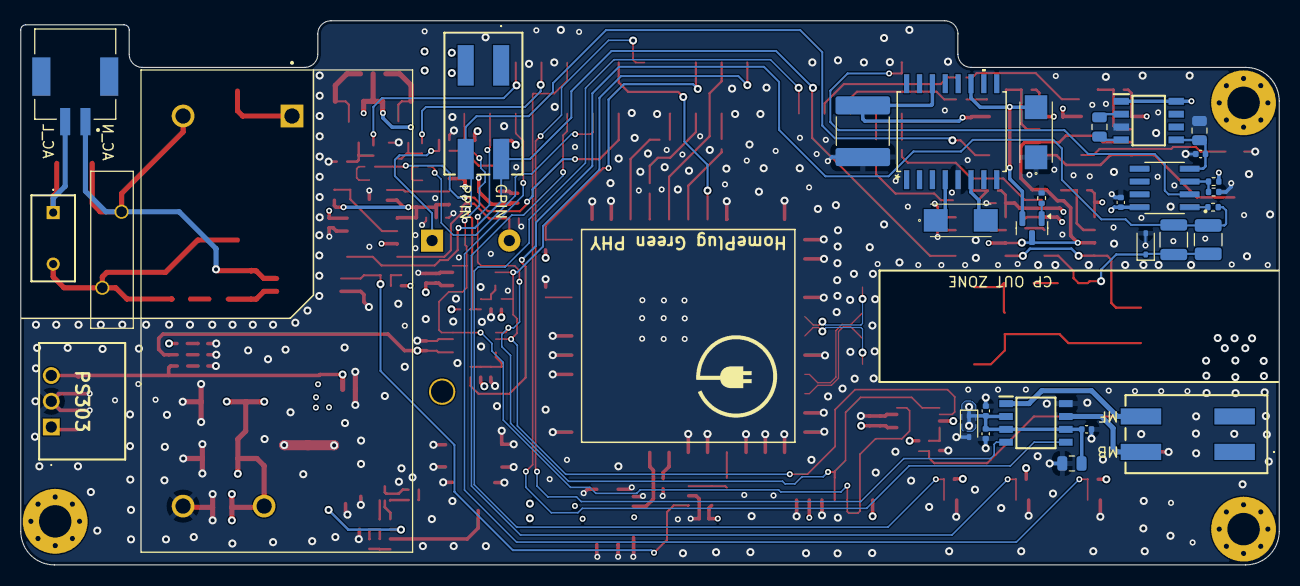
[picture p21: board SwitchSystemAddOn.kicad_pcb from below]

Board: 6 copper layers, 124.2 x 53.7 mm, 182 parts (31 on the bottom side), 102 nets.

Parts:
A501: RED-BEET_2.0
C101, C102, C104, C203, C205, C209, C210, C211, C212, C213, C214, C215, C216, C217, C218, C219, C220, C303, C307, C315, C402, C405, C408, C502, C505, C507: 100n; C_0402_1005Metric
C103, C201, C202, C309, C310, C318: 10u; C_0805_2012Metric
C204: 2uF; C_2220_5750Metric
C206, C207: 100uF; T491C
C208, C506: 1n; C_0402_1005Metric
C301: 10u 20% 16V; EEE1AA220WR
C302, C304, C314, C501: 1u 0805; C_0805_2012Metric
C305, C311, C312, C319, C503: 22u; C_0805_2012Metric
C306: 150u; POSCAP_B1_B1S_B1G_B15G_B2_B2S
C308, C317, C504, C508: 1u; C_0402_1005Metric
C313: 10p; C_0402_1005Metric
C316: 22u TANT; CAPPM7343X310N
C401, C404, C407: 470p; C_0402_1005Metric
C403, C406, C409: 4u7; C_0402_1005Metric
C509, C511: 2n2 2kV; C_1206_3216Metric
C510: 220n; C_0805_2012Metric
C512: 2n2 1kV; C_0805_2012Metric
D101, D102, D103: RED; LED_0402_1005Metric
D104, D105: 1N4148W; D_SOD-123F
D106, D201: GBLC12C; D_SOD-323
D202: 1N4934; D_DO-41_SOD81_P7.62mm_Horizontal
D301: SMBJ20A; DIOM5436X261N
D501: GBLC03C; D_SOD-323
D502: SM4007PL; D_SOD-123F
F101: 3.15A; SS5H315AAPH
H101, H102, H103: MH; MountingHole_3.2mm_M3_Pad_Via
H104: MH; MountingHole_2.2mm_M2_Pad_TopOnly
IC201: TC1044SCOA; SOIC127P600X175-8N
IC301: MP1479GTF-Z; MP1479GTFZ
J101, J102, J104, J107, J111, J113: 1412410000
J103: SM02B-PASS-TBT; JST_SM02B-PASS-TBT_LF__SN_
J105, J106, J108: BM02B-GHS-TBT; JST_GH_BM02B-GHS-TBT_1x02-1MP_P1.25mm_Vertical
J109: BM08B-GHS-TBT; JST_GH_BM08B-GHS-TBT_1x08-1MP_P1.25mm_Vertical
J110: 61004021821; PinSocket_2x20_P2.54mm_Vertical_SMD
J112, J114: SM03B-GHS-TB; JST_GH_SM03B-GHS-TB_1x03-1MP_P1.25mm_Horizontal
L201: 220u; L_1210_3225Metric
L301: MPI40; MPI40_Inductor
L302: HER4027; HER4027-100M
M101: BD6231F-E2; SOIC127P620X160-8N
PS301: LD15-23B12R2; CONV_LD15-23B12R2
PS303: R-78K5.0-2.0; R78K5020
Q101, Q103, Q201, Q202, Q203, Q204, Q205, Q206, Q208: MMBT2222A; SOT-23
Q501: HMHA281
R101, R102, R103, R203, R206, R213, R215, R217, R218, R220, R402, R407, R501, R505: 10k 1%; R_0402_1005Metric
R104, R105, R106, R208, R401, R406: 1k 1%; R_0402_1005Metric
R107, R110, R201, R205, R211, R214, R216, R219, R403, R404, R405: 5k1 5%; R_0402_1005Metric
R108, R502, R503, R504: 0R; R_0402_1005Metric
R109, R202, R204, R307: 100k 1%; R_0402_1005Metric
R207: 56k 1%; R_0402_1005Metric
R209: 240k 1%; R_0402_1005Metric
R210: 82k 1%; R_0402_1005Metric
R212: 220R 1%; R_1210_3225Metric
R221: 1k 5%; R_0805_2012Metric
R222: 2K74 1%; R_0402_1005Metric
R223: 1K3 1%; R_0402_1005Metric
R301: 6R8; RESM17073X710N
R302: 47k 1%; R_0402_1005Metric
R303, R306: 10R 1%; R_0402_1005Metric
R304: 40k2 1%; R_0402_1005Metric
R305: 13k 1%; R_0402_1005Metric
R506: 100R 1%; R_0402_1005Metric
R507: 39k 1%; R_0402_1005Metric
R508: 820k 1/3W; R_0805_2012Metric
RV301: B72214S0351K101; VAR_B72214S0131K101
U201: LF353; SOIC127P599X175-8N
U203, U204, U205, U206, U207, U208: ADG417BR; SOIC-8_3.9x4.9mm_P1.27mm
U209: LT1054CSW-PBF; SO-16_SW_LIT
U401, U402, U403: ADC081C021CIMM; MSOP-8_3x3mm_P0.65mm
U501: LM321; SOT-23-5
U502: YT-35636

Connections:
+3V3: A501.8 (VCC), C303.1, C304.1, C305.1, C306.1, C402.1, C403.1, C405.1, C406.1, C408.1, C409.1, C501.1, C502.1, C503.1, C504.1, C505.1, C507.1, J109.7, L301.2, R101.1, R102.1, R103.1, R104.1, R204.2, R207.2, R401.2, R403.2, R404.2, R405.2, R406.2, R501.1, R506.1, U401.5 (VA), U402.5 (VA), U403.3 (ADR0), U403.5 (VA), U501.5 (V+)
+5V: C213.2, C214.2, C215.2, C217.2, C219.2, C220.2, C319.2, J109.2, J114.2, PS303.3 (+VOUT), R105.1, R203.1, R206.1, R213.1, R215.1, R218.1, R220.1, U203.5 (VL), U204.5 (VL), U205.5 (VL), U206.5 (VL), U207.5 (VL), U208.5 (VL)
+12V: C101.1, C102.1, C103.1, C104.1, C204.1, C205.1, C209.2, C210.2, C211.2, C212.2, C216.2, C218.2, C301.1, C302.1, C314.1, C315.1, C316.1, C318.2, D104.1 (K), D105.1 (K), D106.1 (K), D301.1 (A1), IC201.1 (BOOST), IC201.8 (V+), IC301.1 (VIN), J112.2, M101.2 (VCC_1), M101.3 (VCC_2), M101.6 (VREF), PS301.4 (+VO), PS303.1 (+VIN), R106.1, R307.2, U201.8 (V+), U203.4 (V+), U204.4 (V+), U205.4 (V+), U206.4 (V+), U207.4 (V+), U208.4 (V+), U209.14 (V+)
/3V3_Anode: D101.2 (A), R104.2
/5V_Anode: D102.2 (A), R105.2
/12V_Anode: D103.2 (A), R106.2
/AC_DC_Converter/AC_L_IN: PS301.1 (AC(L)), R301.1
/AC_DC_Converter/BST: C317.1, IC301.4 (BST)
/AC_DC_Converter/BUCK_F1: C313.1, R303.1, R304.2
/AC_DC_Converter/BUCK_F2: C313.2, R302.1, R304.1, R305.2
/AC_DC_Converter/BUCK_F3: C317.2, R306.2
/AC_DC_Converter/EN: IC301.5 (EN), R307.1
/AC_DC_Converter/FB: IC301.6 (FB), R302.2
/AC_DC_Converter/OUT_3v3: C307.1, C308.1, C309.1, C310.1, C311.1, C312.1, L301.1, L302.2, R303.2
/AC_DC_Converter/SW: IC301.2 (SW), L302.1, R306.1
/AC_L: F101.2, R301.2, R508.2, RV301.1
/AC_N: D502.2 (A), J103.1, J107.4, PS301.2 (AC(N)), Q501.2 (K), RV301.2
/ADCPPRead/VIN_ADC1: C404.1, R402.2, U402.4 (VIN)
/ADCPPRead/VIN_ADC3: C407.1, R407.2, U403.4 (VIN)
/But1: J105.1, J110.29, R102.2
/But2: J108.1, J110.11, R103.2
/But3: J106.1, J110.7, R101.2
/CP: J104.2, U203.8, U206.8
/CPControl1: J110.35, R211.2
/CPControl2: J110.37, R201.2
/CPIn: J101.2, U205.1, U206.1
/CPQCA: C511.2, D201.1 (K), L201.1, R212.2, U203.1
/CPRead: C401.1, R207.1, R209.1, R210.2, U401.4 (VIN)
/CPSwitchCircuit/6VON: Q204.3 (C), R215.2, U208.6
/CPSwitchCircuit/9VON: Q202.3 (C), R206.2, U205.6
/CPSwitchCircuit/CAP-: C201.2, IC201.4 (CAP-)
/CPSwitchCircuit/CPIN_T: Q203.3 (C), R213.2, U206.6
/CPSwitchCircuit/CPQCA_T: Q201.3 (C), R203.2, U203.6
/CPSwitchCircuit/Cap+: C201.1, IC201.2 (CAP+)
/CPSwitchCircuit/EV9V: D202.1 (K), R222.1, R223.1
/CPSwitchCircuit/EVSIM_IN: C208.1, D202.2 (A), U205.8
/CPSwitchCircuit/OP_DIV: R202.2, R204.1, U201.3 (+)
/CPSwitchCircuit/OP_OUT: R208.1, U201.1
/CPSwitchCircuit/OP_VIN-: C202.2, C203.1, IC201.5 (VOUT), U201.4 (V-)
/CPSwitchCircuit/PPGEN_T: Q208.3 (C), R220.2, U207.6
/CPSwitchCircuit/PPIN_T: Q205.3 (C), R218.2, U204.6
/CPSwitchCircuit/PWM_OUT: L201.2, R208.2, R209.2, R212.1
/CPSwitchCircuit/VOUT_CPUMP: Q206.3 (C), U203.7 (V-), U204.7 (V-), U205.7 (V-), U206.7 (V-), U207.7 (V-), U208.7 (V-)
/CS: A501.25 (CS_/_GPIO_6), J110.24
/FIN: J110.18, M101.4 (FIN)
/INT: A501.27 (INT_/_GPIO_4), J110.16
/InRelay1: D104.2 (A), J112.1, Q103.3 (C)
/InRelay2: D105.2 (A), J112.3, Q101.3 (C)
/Interrupt: J110.26, R403.1, U401.2 (ALERT), U402.2 (ALERT), U403.2 (ALERT)
/MISO: J110.21, R503.1
/MOSI: J110.19, R504.1
/OUT_M1: J111.4, M101.1 (OUT1)
/OUT_M2: J111.2, M101.7 (OUT2)
/PE: D501.1 (K), J104.4, U502.4
/PP: J102.1, U204.8, U207.8
/PPControl1: J110.31, R219.2
/PPControl2: J110.33, R216.2
/PPIn: J101.4, R401.1, R402.1, U204.1
/PWMCP: J110.38, U201.2 (-)
/RIN: J110.12, M101.5 (RIN)
/RST_YB: A501.20 (RESETN), J110.22, R501.2
/RedBeet/A_AC_L: C512.1, D502.1 (K), Q501.1 (A)
/RedBeet/CP_P: C509.1, D501.2 (A), U502.1
/RedBeet/GPIO1_B: A501.17 (GPIO_1), R505.1
/RedBeet/INV_BUFF: C506.2, U501.3 (-), U501.4
/RedBeet/MISO_B: A501.24 (MISO), R503.2
/RedBeet/MOSI_B: A501.23 (MOSI), R504.2
/RedBeet/RX_N: A501.33 (RXN), U502.8
/RedBeet/RX_P: A501.34 (RXP), U502.5
/RedBeet/SCLK_B: A501.26 (SCLK), R502.2
/RedBeet/TX_N: A501.36 (TXN), U502.7
/RedBeet/TX_P: A501.37 (TXP), U502.6
/RedBeet/V_DIV: C508.1, R506.2, R507.1
/RedBeet/ZC_IN: A501.4 (ZC_IN), C506.1
/RedBeet/ZC_OPTO: C510.1, Q501.4 (C), R507.2, U501.1 (+)
/RelayCont1: J110.10, R110.1
/RelayCont2: J110.8, R107.1
/SCL: J109.4, J110.5, R405.1, U401.1 (SCL), U402.1 (SCL), U403.1 (SCL)
/SCLK: J110.23, R502.1
/SDA: J109.5, J109.6, J110.3, R404.1, U401.8 (SDA), U402.8 (SDA), U403.8 (SDA)
/SimReady: J110.13, R214.2
/SimSwitch: J110.15, R205.2
/TEMP_SENSE: J113.2, R406.1, R407.1
GND: A501.1 (GND), A501.2 (GND), A501.3 (GND), A501.5 (GND), A501.6 (GND), A501.7 (GND), A501.10 (GND), A501.13 (EPHY_RX_N), A501.14 (EPHY_RX_P), A501.15 (GND), A501.21 (GND), A501.22 (GND), A501.28 (GND), A501.29 (GND), A501.30 (GND), A501.31 (GND), A501.32 (GND), A501.35 (GND), A501.38 (GND), A501.39 (GND), A501.40 (TPAD), C101.2, C102.2, C103.2, C104.2, C202.1, C203.2, C204.2, C205.2, C207.1, C208.2, C209.1, C210.1, C211.1, C212.1, C213.1, C214.1, C215.1, C216.1, C217.1, C218.1, C219.1, C220.1, C301.2, C302.2, C303.2, C304.2, C305.2, C306.2, C307.2, C308.2, C309.2, C310.2, C311.2, C312.2, C314.2, C315.2, C316.2, C318.1, C319.1, C401.2, C402.2, C403.2, C404.2, C405.2, C406.2, C407.2, C408.2, C409.2, C501.2, C502.2, C503.2, C504.2, C505.2, C507.2, C508.2, C510.2, D101.1 (K), D102.1 (K), D103.1 (K), D106.2 (A), D201.2 (A), D301.2 (A2), IC201.3 (GND), IC301.3 (GND), J104.3, J105.2, J105.MP (MountPin), J106.2, J106.MP (MountPin), J108.2, J108.MP (MountPin), J109.1, J109.3, J109.MP (MountPin), J110.6, J110.9, J110.14, J110.20, J110.25, J110.30, J110.34, J110.39, J112.MP (MountPin), J113.4, J114.3, J114.MP (MountPin), M101.8 (GND), PS301.3 (-VO), PS303.2 (GND), Q101.2 (E), Q103.2 (E), Q201.2 (E), Q202.2 (E), Q203.2 (E), Q204.2 (E), Q205.2 (E), Q208.2 (E), Q501.3 (E), R108.1, R109.2, R202.1, R210.1, R217.2, R221.1, R222.2, R305.1, R505.2, U203.3 (GND), U204.3 (GND), U205.3 (GND), U206.3 (GND), U207.3 (GND), U208.3 (GND), U208.8, U209.5 (GND), U401.3 (ADR0), U401.7 (GND), U402.7 (GND), U403.7 (GND), U501.2 (V-)
unnamed: C509.2, C511.1
unnamed: C512.2, R508.1
unnamed: F101.1, J103.2, J107.2
unnamed: Q101.1 (B), R109.1, R110.2
unnamed: Q103.1 (B), R107.2, R108.2
unnamed: Q201.1 (B), R201.1
unnamed: Q202.1 (B), R205.1
unnamed: Q203.1 (B), R211.1
unnamed: Q204.1 (B), R214.1
unnamed: Q205.1 (B), R216.1
unnamed: Q206.1 (B), R217.1
unnamed: C207.2, Q206.2 (E), U209.11 (VOUT)
unnamed: Q208.1 (B), R219.1
unnamed: R221.2, U207.1
unnamed: R223.2, U208.1
unnamed: C206.1, U209.4 (CAP+)
unnamed: C206.2, U209.6 (CAP-)
VCOM: J110.2, J110.4, J114.1
